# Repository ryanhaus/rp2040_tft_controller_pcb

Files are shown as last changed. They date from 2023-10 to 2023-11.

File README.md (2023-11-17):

# rp2040_tft_controller_pcb
 RP2040-based controller board for the [MI0284QT-11 TFT LCD](https://www.adafruit.com/product/1774) (ILI9341 controller chip) designed in KiCad.<br />
 Future plans are to modify this board to have an FPGA controlling the actual LCD, acting as a GPU, allowing the RP2040 (or another microcontroller) to run more complex programs, see my [ili9341_controller repository](https://github.com/ryanhaus/ili9341_controller).

## PCB Screenshots
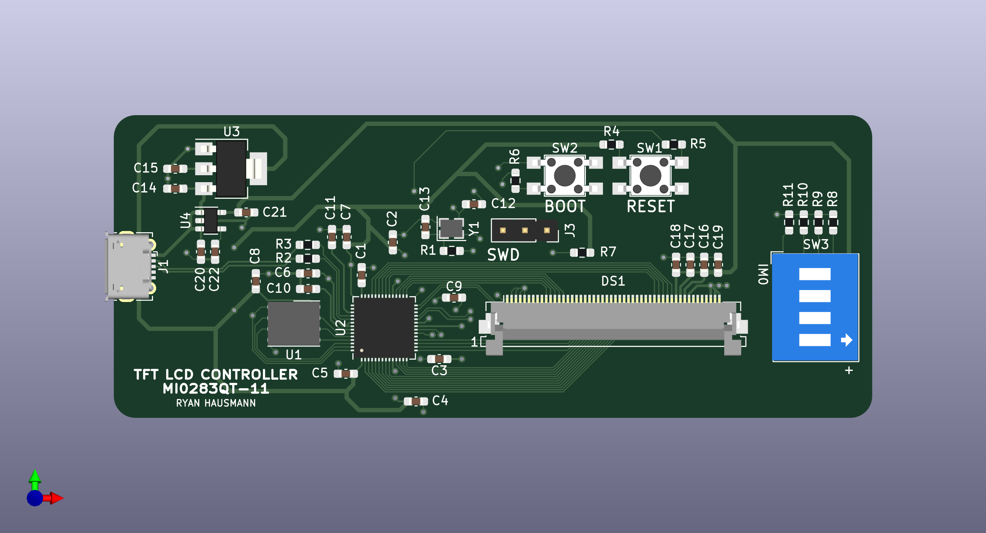
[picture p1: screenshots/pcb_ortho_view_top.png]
Top view of PCB


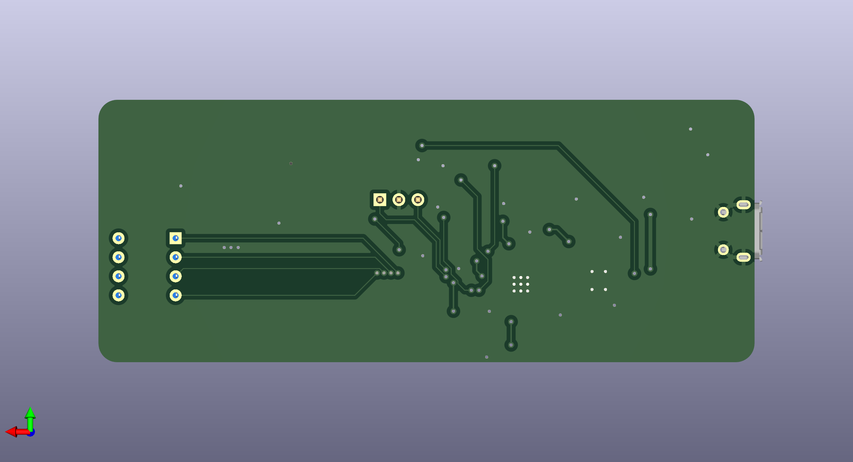
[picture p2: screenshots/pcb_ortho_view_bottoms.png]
Bottom view of PCB


## Schematics
Schematics for this PCB can be found in the top directory.<br/>
PDF printouts can be found in the [pdfs](https://github.com/ryanhaus/rp2040_tft_controller_pcb/tree/99923349eaa0201b7b87c9602e28e256294b100d/pdfs) folder.

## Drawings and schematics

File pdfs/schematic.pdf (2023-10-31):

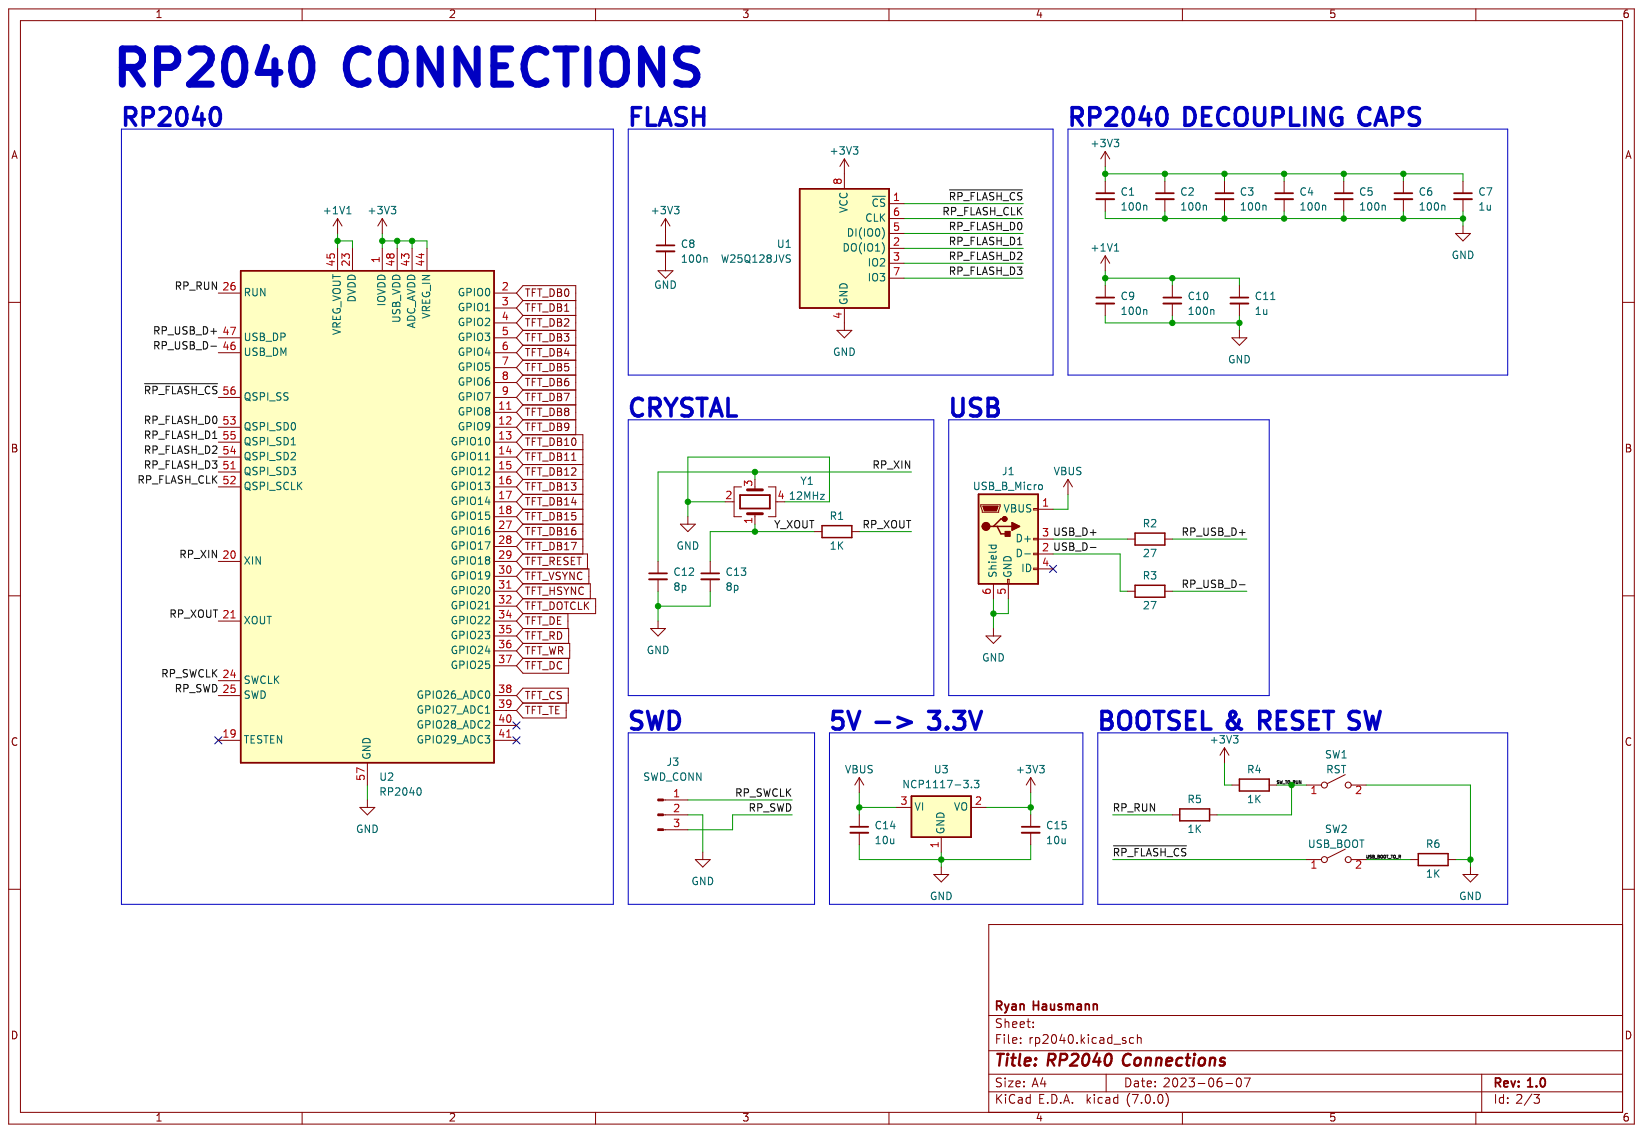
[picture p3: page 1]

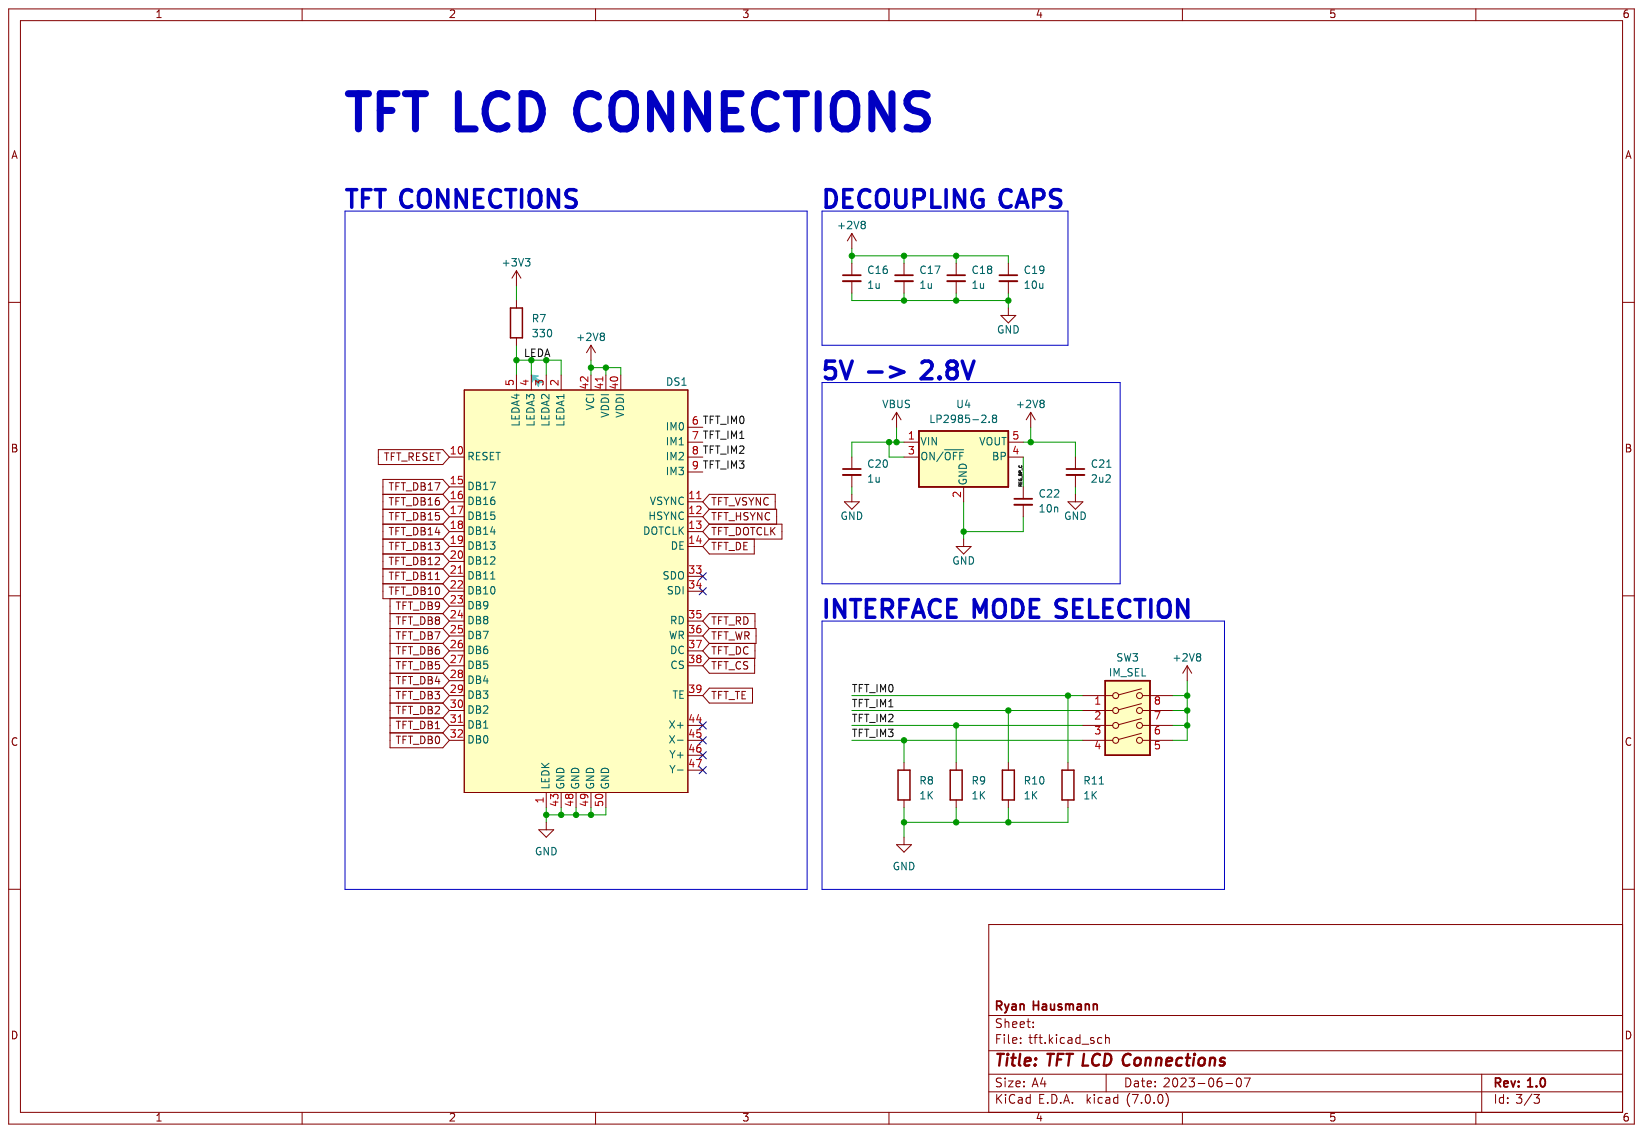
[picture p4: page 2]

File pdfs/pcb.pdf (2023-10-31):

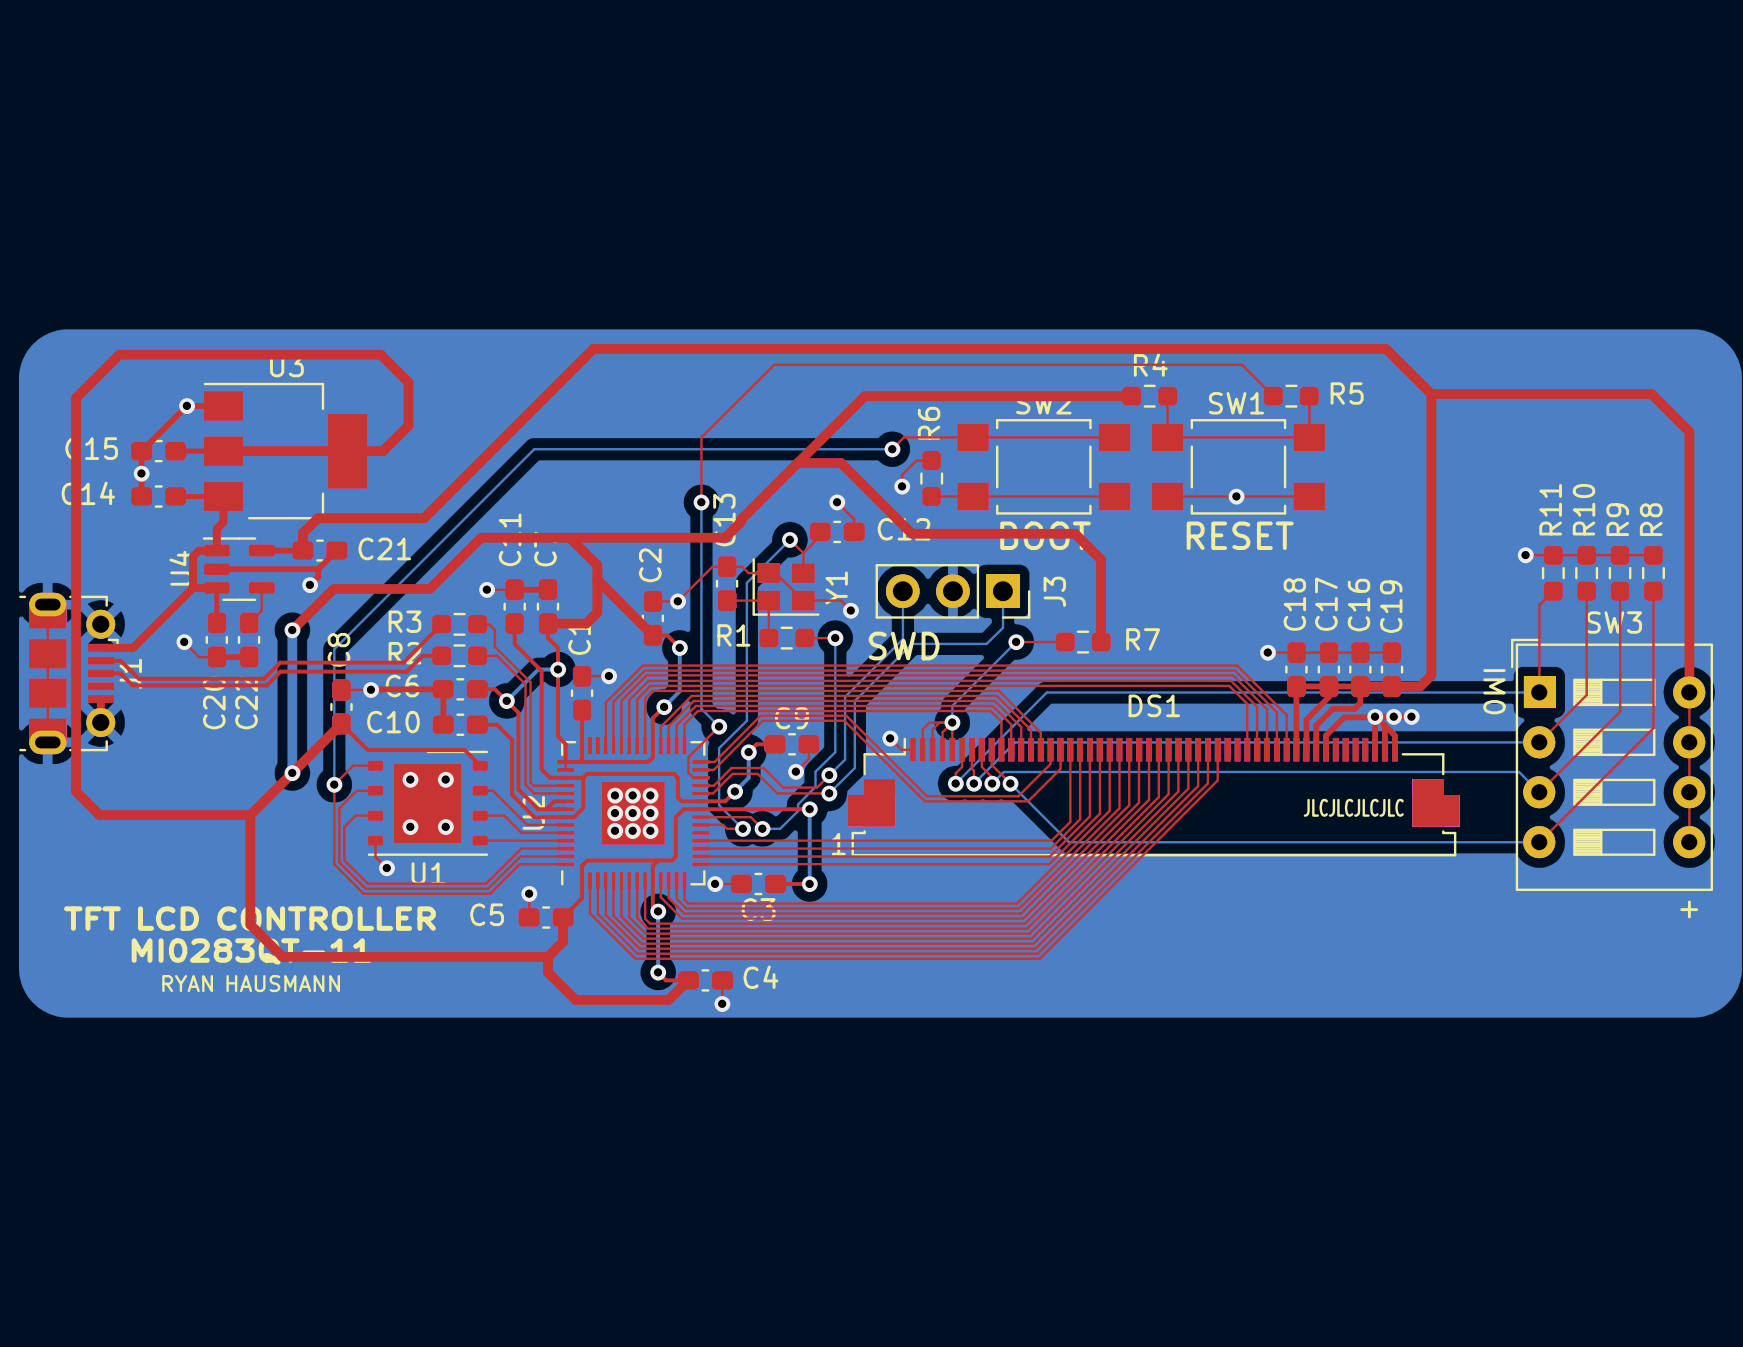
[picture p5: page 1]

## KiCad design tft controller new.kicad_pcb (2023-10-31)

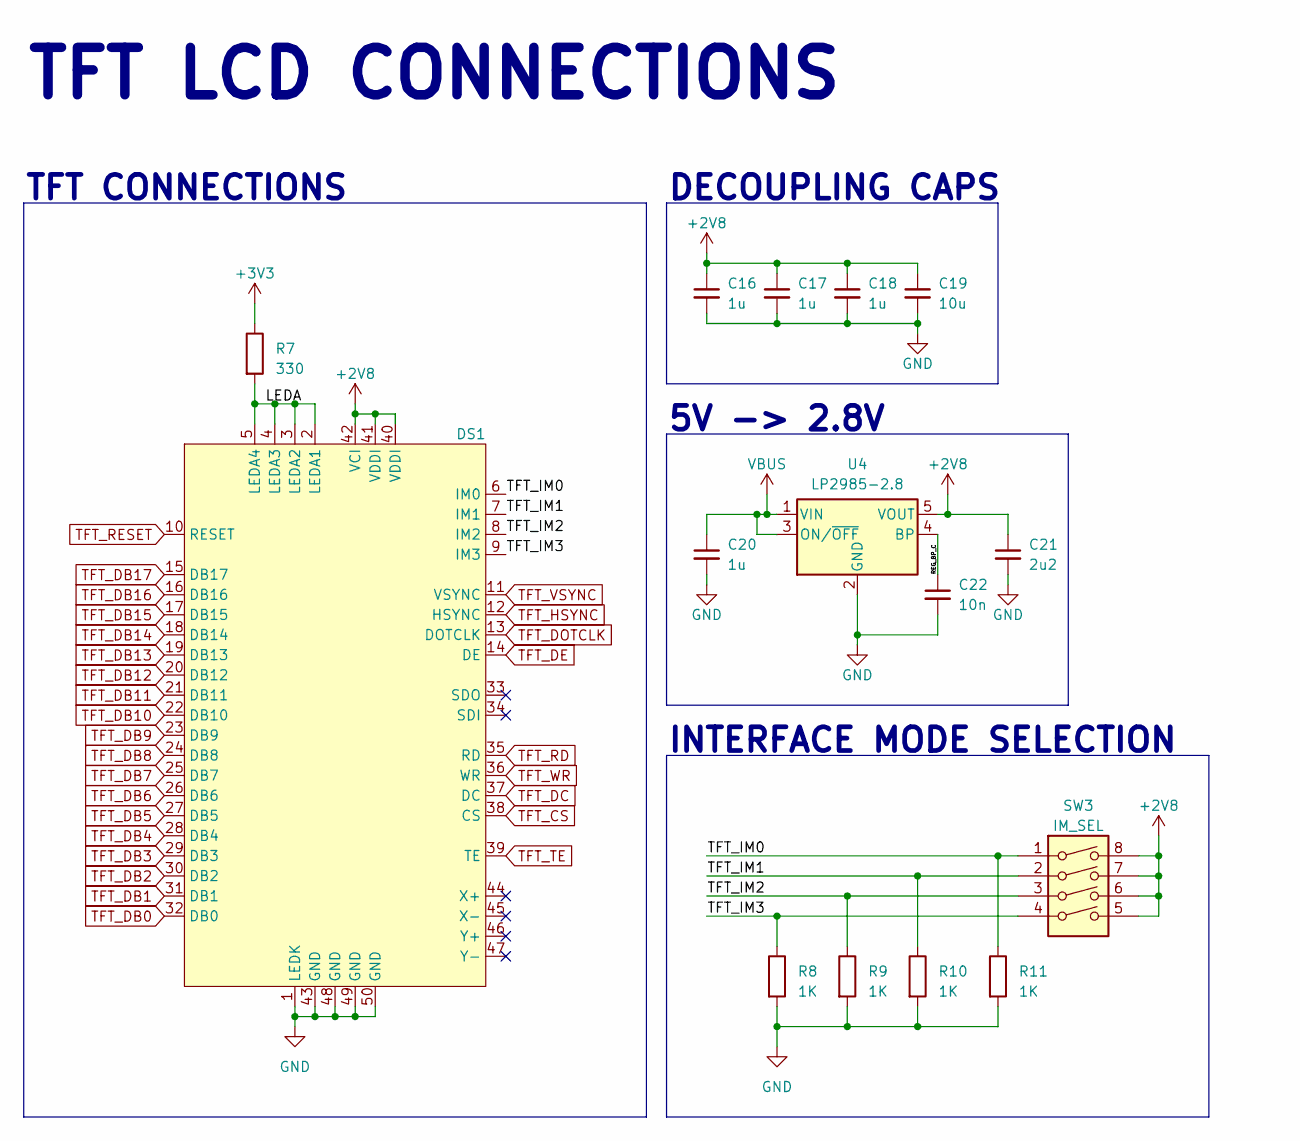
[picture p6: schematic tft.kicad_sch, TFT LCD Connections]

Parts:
C16, C17, C18, C20: 1u; C_0603_1608Metric_Pad1.08x0.95mm_HandSolder
C19: 10u; C_0603_1608Metric_Pad1.08x0.95mm_HandSolder
C21: 2u2; C_0603_1608Metric_Pad1.08x0.95mm_HandSolder
C22: 10n; C_0603_1608Metric_Pad1.08x0.95mm_HandSolder
DS1: Molex_54132-5033_1x50-1MP_P0.5mm_Horizontal
R7: 330; R_0603_1608Metric_Pad0.98x0.95mm_HandSolder
R8, R9, R10, R11: 1K; R_0603_1608Metric_Pad0.98x0.95mm_HandSolder
SW3: IM_SEL; SW_DIP_SPSTx04_Slide_9.78x12.34mm_W7.62mm_P2.54mm
U4: LP2985-2.8; SOT-23-5

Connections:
+2V8: C16.1, C17.1, C18.1, C19.1, C21.1, DS1.40 (VDDI), DS1.41 (VDDI), DS1.42 (VCI), SW3.5, SW3.6, SW3.7, SW3.8, U4.5 (VOUT)
+3V3: R7.1; also elsewhere on the board
/TFT LCD Connections/LEDA: DS1.2 (LEDA1), DS1.3 (LEDA2), DS1.4 (LEDA3), DS1.5 (LEDA4), R7.2
/TFT LCD Connections/REG_BP_C: C22.1, U4.4 (BP)
/TFT LCD Connections/TFT_IM0: DS1.6 (IM0), R11.1, SW3.1
/TFT LCD Connections/TFT_IM1: DS1.7 (IM1), R10.1, SW3.2
/TFT LCD Connections/TFT_IM2: DS1.8 (IM2), R9.1, SW3.3
/TFT LCD Connections/TFT_IM3: DS1.9 (IM3), R8.1, SW3.4
GND: C16.2, C17.2, C18.2, C19.2, C20.2, C21.2, C22.2, DS1.1 (LEDK), DS1.43 (GND), DS1.48 (GND), DS1.49 (GND), DS1.50 (GND), R8.2, R9.2, R10.2, R11.2, U4.2 (GND); also elsewhere on the board
TFT_CS: DS1.38 (CS); also elsewhere on the board
TFT_DB0: DS1.32 (DB0); also elsewhere on the board
TFT_DB1: DS1.31 (DB1); also elsewhere on the board
TFT_DB2: DS1.30 (DB2); also elsewhere on the board
TFT_DB3: DS1.29 (DB3); also elsewhere on the board
TFT_DB4: DS1.28 (DB4); also elsewhere on the board
TFT_DB5: DS1.27 (DB5); also elsewhere on the board
TFT_DB6: DS1.26 (DB6); also elsewhere on the board
TFT_DB7: DS1.25 (DB7); also elsewhere on the board
TFT_DB8: DS1.24 (DB8); also elsewhere on the board
TFT_DB9: DS1.23 (DB9); also elsewhere on the board
TFT_DB10: DS1.22 (DB10); also elsewhere on the board
TFT_DB11: DS1.21 (DB11); also elsewhere on the board
TFT_DB12: DS1.20 (DB12); also elsewhere on the board
TFT_DB13: DS1.19 (DB13); also elsewhere on the board
TFT_DB14: DS1.18 (DB14); also elsewhere on the board
TFT_DB15: DS1.17 (DB15); also elsewhere on the board
TFT_DB16: DS1.16 (DB16); also elsewhere on the board
TFT_DB17: DS1.15 (DB17); also elsewhere on the board
TFT_DC: DS1.37 (DC); also elsewhere on the board
TFT_DE: DS1.14 (DE); also elsewhere on the board
TFT_DOTCLK: DS1.13 (DOTCLK); also elsewhere on the board
TFT_HSYNC: DS1.12 (HSYNC); also elsewhere on the board
TFT_RD: DS1.35 (RD); also elsewhere on the board
TFT_RESET: DS1.10 (RESET); also elsewhere on the board
TFT_TE: DS1.39 (TE); also elsewhere on the board
TFT_VSYNC: DS1.11 (VSYNC); also elsewhere on the board
TFT_WR: DS1.36 (WR); also elsewhere on the board
VBUS: C20.1, U4.1 (VIN), U4.3 (ON/~OFF); also elsewhere on the board

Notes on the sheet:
TFT CONNECTIONS
DECOUPLING CAPS
INTERFACE MODE SELECTION
TFT LCD CONNECTIONS
5V -> 2.8V

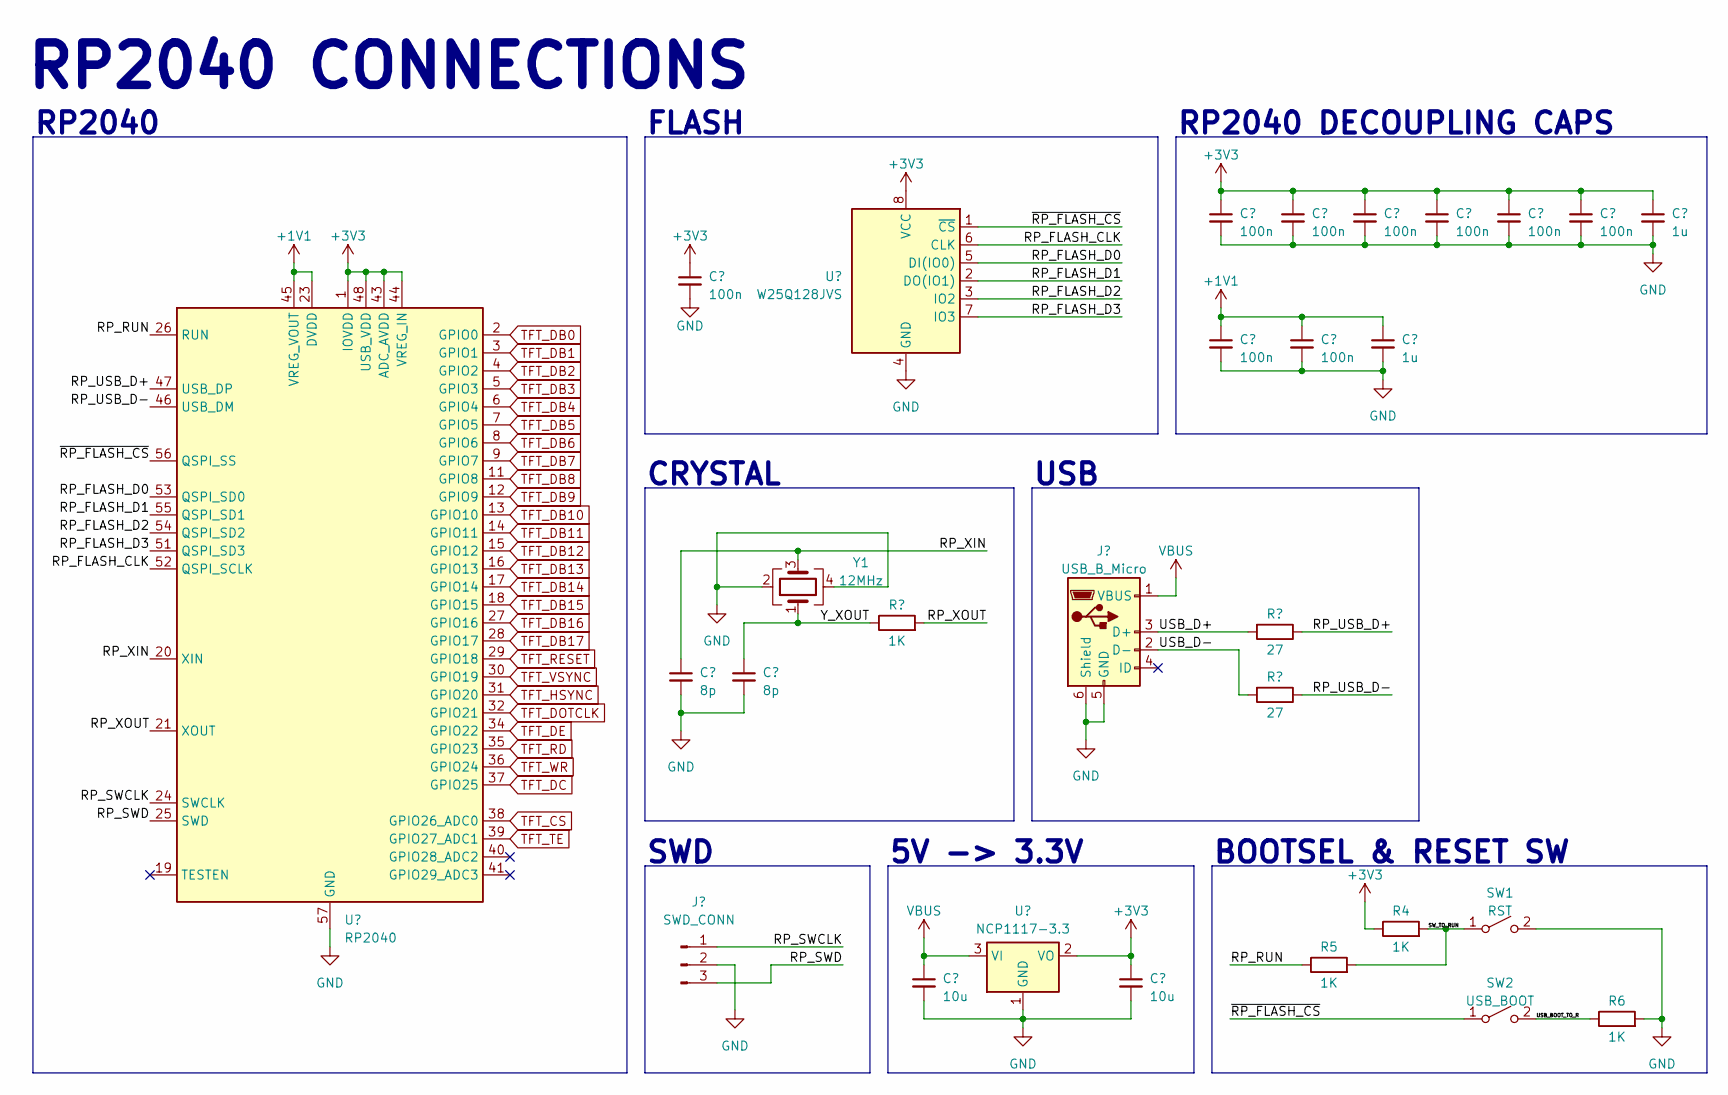
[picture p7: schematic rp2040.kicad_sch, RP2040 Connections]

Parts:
C1, C2, C3, C4, C5, C6, C8, C9, C10: 100n; C_0603_1608Metric_Pad1.08x0.95mm_HandSolder
C7, C11: 1u; C_0603_1608Metric_Pad1.08x0.95mm_HandSolder
C12, C13: 8p; C_0603_1608Metric_Pad1.08x0.95mm_HandSolder
C14, C15: 10u; C_0603_1608Metric_Pad1.08x0.95mm_HandSolder
J1: USB_B_Micro; USB_Micro-B_Molex-105017-0001
J3: SWD_CONN; PinSocket_1x03_P2.54mm_Vertical
R1, R4, R5, R6: 1K; R_0603_1608Metric_Pad0.98x0.95mm_HandSolder
R2, R3: 27; R_0603_1608Metric_Pad0.98x0.95mm_HandSolder
SW1: RST; SW_SPST_TL3305A
SW2: USB_BOOT; SW_SPST_TL3305A
U1: W25Q128JVS; WSON-8-1EP_6x5mm_P1.27mm_EP3.4x4mm
U2: RP2040; QFN-56-1EP_7x7mm_P0.4mm_EP3.2x3.2mm
U3: NCP1117-3.3; SOT-223-3_TabPin2
Y1: 12MHz; Crystal_SMD_2520-4Pin_2.5x2.0mm

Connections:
+1V1: C9.1, C10.1, C11.1, U2.23 (DVDD), U2.45 (VREG_VOUT), U2.50 (DVDD)
+3V3: C1.1, C2.1, C3.1, C4.1, C5.1, C6.1, C7.1, C8.1, C15.1, R4.1, U1.8 (VCC), U2.1 (IOVDD), U2.10 (IOVDD), U2.22 (IOVDD), U2.33 (IOVDD), U2.42 (IOVDD), U2.43 (ADC_AVDD), U2.44 (VREG_IN), U2.48 (USB_VDD), U2.49 (IOVDD), U3.2 (VO); also elsewhere on the board
/RP2040 Connections/RP_FLASH_CLK: U1.6 (CLK), U2.52 (QSPI_SCLK)
/RP2040 Connections/RP_FLASH_D0: U1.5 (DI(IO0)), U2.53 (QSPI_SD0)
/RP2040 Connections/RP_FLASH_D1: U1.2 (DO(IO1)), U2.55 (QSPI_SD1)
/RP2040 Connections/RP_FLASH_D2: U1.3 (IO2), U2.54 (QSPI_SD2)
/RP2040 Connections/RP_FLASH_D3: U1.7 (IO3), U2.51 (QSPI_SD3)
/RP2040 Connections/RP_RUN: R5.1, U2.26 (RUN)
/RP2040 Connections/RP_SWCLK: J3.1, U2.24 (SWCLK)
/RP2040 Connections/RP_SWD: J3.3, U2.25 (SWD)
/RP2040 Connections/RP_USB_D+: R2.1, U2.47 (USB_DP)
/RP2040 Connections/RP_USB_D-: R3.1, U2.46 (USB_DM)
/RP2040 Connections/RP_XIN: C12.1, U2.20 (XIN), Y1.3
/RP2040 Connections/RP_XOUT: R1.2, U2.21 (XOUT)
/RP2040 Connections/SW_TO_RUN: R4.2, R5.2, SW1.1 (A)
/RP2040 Connections/USB_BOOT_TO_R: R6.1, SW2.2 (B)
/RP2040 Connections/USB_D+: J1.3 (D+), R2.2
/RP2040 Connections/USB_D-: J1.2 (D-), R3.2
/RP2040 Connections/Y_XOUT: C13.1, R1.1, Y1.1
/RP2040 Connections/~RP_FLASH_CS: SW2.1 (A), U1.1 (~CS), U2.56 (QSPI_SS)
GND: C1.2, C2.2, C3.2, C4.2, C5.2, C6.2, C7.2, C8.2, C9.2, C10.2, C11.2, C12.2, C13.2, C14.2, C15.2, J1.5 (GND), J1.6 (Shield), J3.2, R6.2, SW1.2 (B), U1.4 (GND), U1.9, U2.57 (GND), U3.1 (GND), Y1.2, Y1.4; also elsewhere on the board
TFT_CS: U2.38 (GPIO26_ADC0); also elsewhere on the board
TFT_DB0: U2.2 (GPIO0); also elsewhere on the board
TFT_DB1: U2.3 (GPIO1); also elsewhere on the board
TFT_DB2: U2.4 (GPIO2); also elsewhere on the board
TFT_DB3: U2.5 (GPIO3); also elsewhere on the board
TFT_DB4: U2.6 (GPIO4); also elsewhere on the board
TFT_DB5: U2.7 (GPIO5); also elsewhere on the board
TFT_DB6: U2.8 (GPIO6); also elsewhere on the board
TFT_DB7: U2.9 (GPIO7); also elsewhere on the board
TFT_DB8: U2.11 (GPIO8); also elsewhere on the board
TFT_DB9: U2.12 (GPIO9); also elsewhere on the board
TFT_DB10: U2.13 (GPIO10); also elsewhere on the board
TFT_DB11: U2.14 (GPIO11); also elsewhere on the board
TFT_DB12: U2.15 (GPIO12); also elsewhere on the board
TFT_DB13: U2.16 (GPIO13); also elsewhere on the board
TFT_DB14: U2.17 (GPIO14); also elsewhere on the board
TFT_DB15: U2.18 (GPIO15); also elsewhere on the board
TFT_DB16: U2.27 (GPIO16); also elsewhere on the board
TFT_DB17: U2.28 (GPIO17); also elsewhere on the board
TFT_DC: U2.37 (GPIO25); also elsewhere on the board
TFT_DE: U2.34 (GPIO22); also elsewhere on the board
TFT_DOTCLK: U2.32 (GPIO21); also elsewhere on the board
TFT_HSYNC: U2.31 (GPIO20); also elsewhere on the board
TFT_RD: U2.35 (GPIO23); also elsewhere on the board
TFT_RESET: U2.29 (GPIO18); also elsewhere on the board
TFT_TE: U2.39 (GPIO27_ADC1); also elsewhere on the board
TFT_VSYNC: U2.30 (GPIO19); also elsewhere on the board
TFT_WR: U2.36 (GPIO24); also elsewhere on the board
VBUS: C14.1, J1.1 (VBUS), U3.3 (VI); also elsewhere on the board

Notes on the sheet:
CRYSTAL
RP2040 DECOUPLING CAPS
USB
RP2040 CONNECTIONS
BOOTSEL & RESET SW
SWD
5V -> 3.3V
RP2040
FLASH

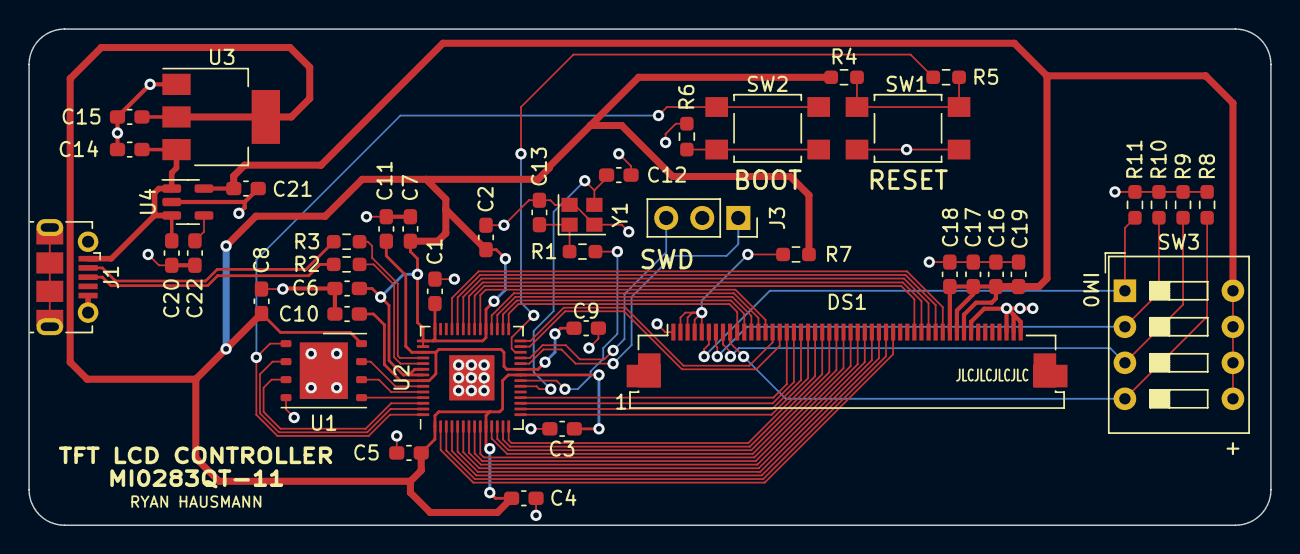
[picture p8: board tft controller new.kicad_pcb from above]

Board: 4 copper layers, 87.6 x 35.0 mm, 44 parts (0 on the bottom side), 57 nets.
